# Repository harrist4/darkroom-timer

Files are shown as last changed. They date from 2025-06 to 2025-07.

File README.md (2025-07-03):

# Darkroom Dual Timer

A USB-powered stopwatch + countdown timer designed for darkroom and general timing tasks.  
Features a clear LED display, tactile button interface, audible feedback, and ultra-low sleep mode.

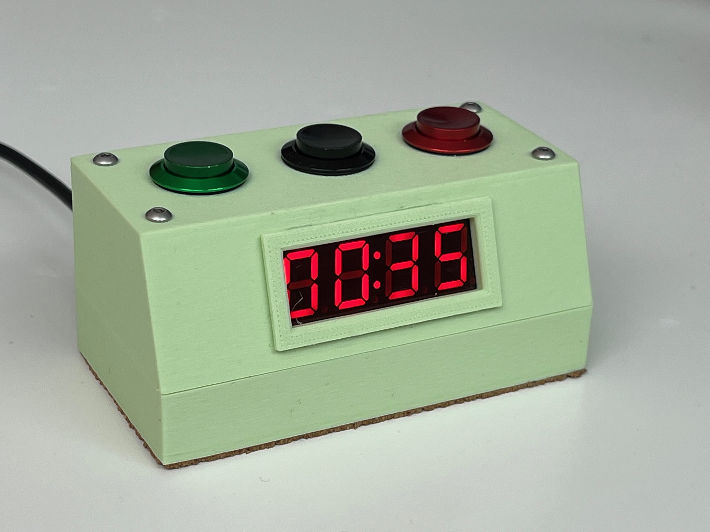
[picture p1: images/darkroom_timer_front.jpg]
Assembled Darkroom Timer


---

## Features

- Stopwatch and countdown timer modes
- Long-press and chord-based controls
- Sleep mode with wake-on-button
- Audible ticks and alarm tones
- Powered by any USB-C charger using an external 5V trigger module
- Clean UV-resin bezel, red optical gel

---

## Modes
### Global Controls
- **Green + Black** — Enable ticking
- **Red + Black** — Disable ticking
- **Green + Red** — Toggle between Stopwatch and Countdown (Alarm) modes
- **Red (D4, long press)** — Power off

### Stopwatch Mode
- **Green (D2)** — Start
- **Red (D4)** — Stop
- **Black (D3)** — Reset

### Countdown Timer Mode
- **Black (D3)** — Add 1 minute (tap), or rapid 5min increments (hold)
- **Black (D3, long press)** — Reset to 00:00
- **Green (D2)** — Start countdown
- **Red (D4)** — Stop countdown

---

## Wiring Summary

| Arduino Pin | Function | Notes |
|---|---|---|
| D2 * | Green Button | Start / wake / tick toggle (INT0: wake from sleep) |
| D3 * | Black Button | Add time / reset timer (INT1: wake from sleep) |
| D4 | Red Button | Stop / sleep / mode toggle |
| D5 | Buzzer | Passive buzzer tone output |
| D6 | TM1637 CLK | 4-digit display clock |
| D7 | TM1637 DIO | 4-digit display data |

\* Pins D2 and D3 are used for sleep wake interrupts INT0 and INT1

- Buttons are connected to GND and use `INPUT_PULLUP`
- Buzzer connects to D5 and GND
- Display uses TM1637 2-wire serial

---

## Power

- Powered via 5V USB-C trigger module
- USB-C powers Nano and display via 5V/GND pins
- Nano’s onboard USB port is unused
- Ideal for portable, battery-backed use

---

## 3D Printed Case

- STL files in `/3D/` folder
  - Top: `darkroom-timer-Case Top.stl`
  - Bottom: `darkroom-timer-Case Bottom.stl`
  - Bezel: `darkroom-timer-Bezel.stl` (step-backed for UV resin)

### Assembly Notes
- Internal parts secured with hot glue (release with IPA)
- Bezel glued with Bondic UV resin into side groove
- Red lighting gel sits under bezel over LED display

---

## Files

- `Arduino/DarkroomDualTimer/DarkroomDualTimer.ino`
- `3D/*.stl` and FreeCAD source
- `parts_list.md` with all required materials

### Required Arduino Libraries

This project depends on two Arduino libraries:

- **TM1637Display** by Avishorp — for driving the 4-digit LED display
- **ezButton** by ArduinoGetStarted — for reliable button press handling and debouncing

To install these libraries:

1. Open the Arduino IDE
2. Go to **Sketch → Include Library → Manage Libraries...**
3. In the Library Manager:
   - Search for **“TM1637Display”** and click **Install**
   - Search for **“ezButton”** and click **Install**

Alternatively, if you're using the Arduino CLI:

```bash
arduino-cli lib install "TM1637Display"
arduino-cli lib install "ezButton"
```

Make sure these libraries are available in your environment before compiling the sketch.

---

For parts, assembly tips, and adhesive guidance, see [`parts_list.md`](parts_list.md).

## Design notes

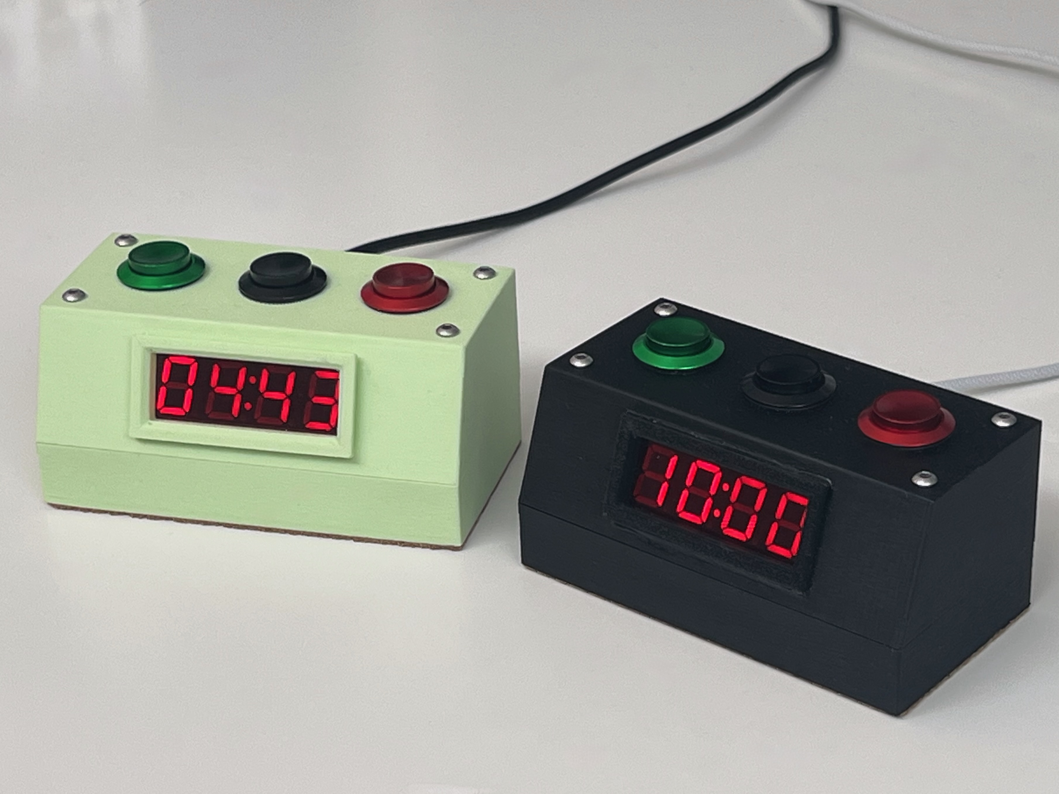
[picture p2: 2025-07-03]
images/darkroom_timers.jpeg

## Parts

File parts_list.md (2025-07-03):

# Parts List for Darkroom Timer Project

This project uses commonly available components to build a USB-powered stopwatch-style darkroom timer with a 4-digit LED display, audible tick, and a 3-button interface.

---

## Core Components

- **Arduino Nano V3.0** — ATmega328P with CH340 USB interface
- **Nano I/O Shield** — Terminal adapter expansion board for clean wiring
- **TM1637 4-Digit Display Module** — 0.56" red LED with built-in serial driver
- **Passive Buzzer** — 5V electromagnetic beeper (e.g., CYT1008)
- **Momentary Push Buttons (x3)** — 19mm metal, SPST, momentary action, screw terminal (Red, Green, Black)
- **USB-C Power Trigger Module** — Converts power from a USB-C charger into a steady 5V output for the timer (e.g., AITRIP 5A USB-C PD trigger board)

---

## Mounting and Wiring

- **M3 Screws (x4)** — Used to assemble the case
- **M3 Threaded Inserts (x4)** — Heat-set into plastic for secure case fastening
- **Adhesive Cork Sheet** — 1mm thick, applied to base for grip and surface protection
- **Wiring** — Flexible stranded hookup wire; connectors are up to builder preference

---

## Optical Component

- **Red Lighting Gel Filter** — 8.5" x 11" transparent red correction gel for safelight compatibility  
  - Example: *Transparent Color Red Correction Lighting Gel Filter 8.5 x 11-Inches Red Gel Light Filter Plastic Film Sheets*

---

## Adhesives and Assembly Aids

- **Hot Glue** — Used to secure internal components (Nano, display, USB-C module) to the case interior  
  - Easily released with a spray of isopropyl alcohol (IPA)
- **Bondic UV Resin Kit** — Used to affix the bezel cleanly without fogging or warping the red gel  
  - UV-accessible groove in the bezel makes this straightforward

---

## STL and Source Files

- FreeCAD source and STL files are located in the `3D/` directory  
  - Bezel: `darkroom-timer-Bezel.stl` (stepped design for UV resin)
  - Top/Bottom Case: `darkroom-timer-Case Top.stl`, `darkroom-timer-Case Bottom.stl`
- Arduino sketches are located in the `Arduino/` directory  
  - Main project: `Arduino/DarkroomDualTimer/DarkroomDualTimer.ino`
  - Demo/test sketch: `Arduino/VIsForVictory/VIsForVictory.ino`

---

For assembly instructions, wiring diagrams, and additional images, see the `README.md`.

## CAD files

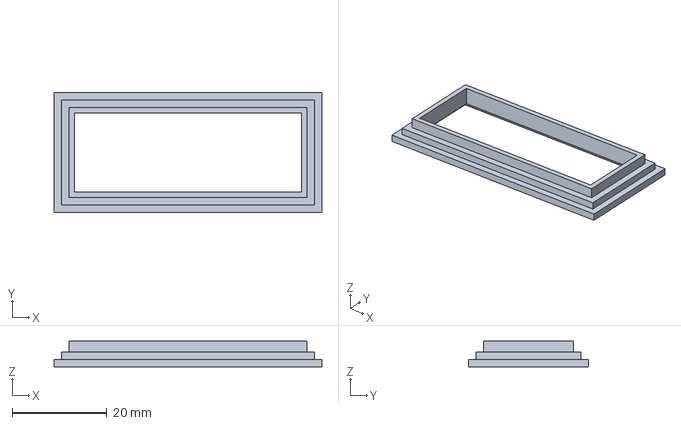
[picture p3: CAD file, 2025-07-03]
3D/darkroom-timer.FCStd
56.5 x 25.4 x 5.46 mm

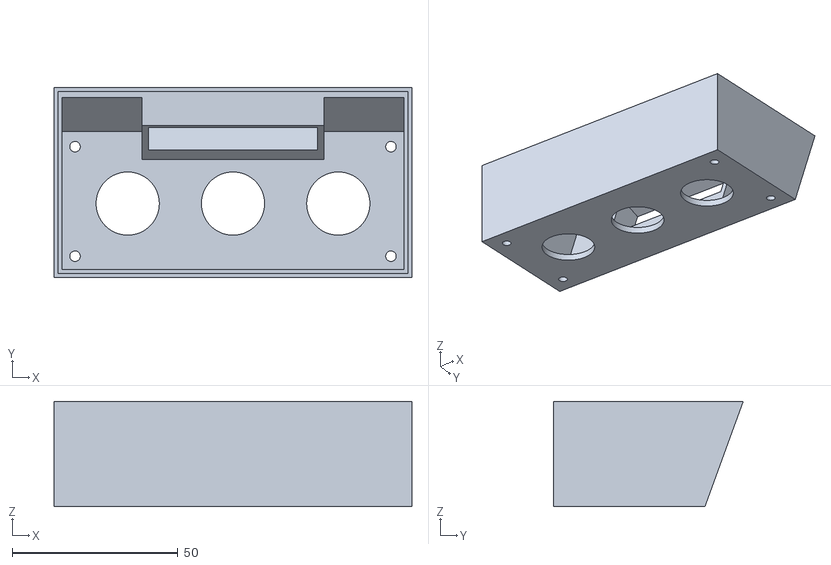
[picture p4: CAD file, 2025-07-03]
3D/darkroom-timer-Case Top.stl
107.9 x 57.2 x 31.8

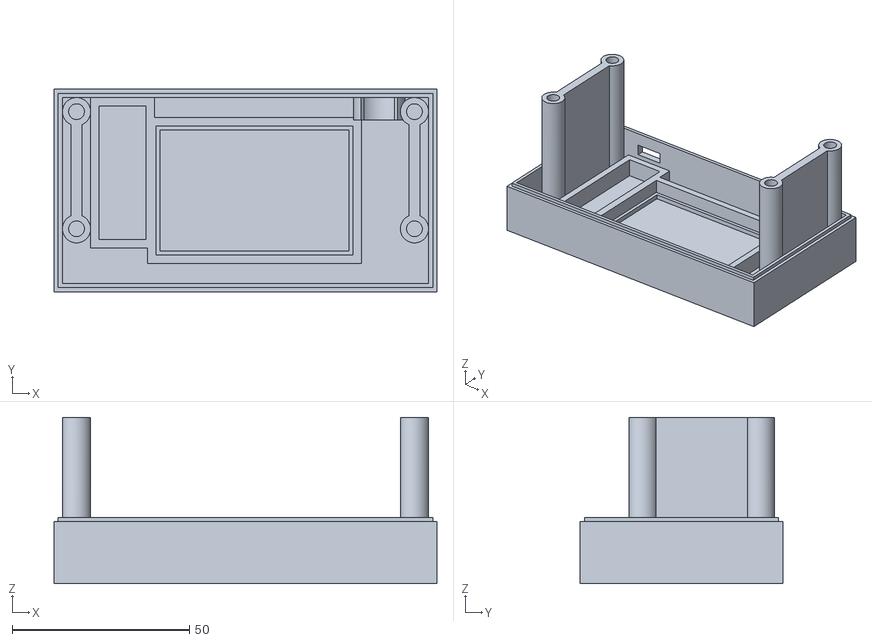
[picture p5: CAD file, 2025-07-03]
3D/darkroom-timer-Case Bottom.stl
107.9 x 57.2 x 46.8

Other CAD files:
3D/darkroom-timer-Bezel.stl

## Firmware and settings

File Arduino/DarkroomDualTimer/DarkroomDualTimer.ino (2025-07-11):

// ==================================================
// DarkroomDualTimer.ino
// Combined Stopwatch + Countdown Timer for Darkroom
// Features: mode switching, arpeggio tones, TM1637 display
// ==================================================

#include <ezButton.h>
#include <TM1637Display.h>
#include <EEPROM.h>
#include <avr/sleep.h>

// === CONFIGURATION ===
const int EEPROM_ADDR_MODE = 0;       // stores currentMode
const int EEPROM_ADDR_TICK = 1;       // stores tickEnabled
const int EEPROM_ADDR_INIT     = 100;  // a safe location for our marker
const byte EEPROM_MAGIC_VALUE = 0x42; // arbitrary non-zero value

const int NUM_BUTTONS = 3;
const unsigned long LONG_PRESS_THRESHOLD_MILLIS = 500UL;
const unsigned long CHORD_TIME_WINDOW_MILLIS = 100UL;

const unsigned long TICK_INTERVAL_MILLIS = 1000UL; // Timer tick every second

const unsigned long STOPWATCH_STOPPED_RESET_MILLIS = 30UL * 1000UL; // Time after stop when timer resets automatically
const unsigned long IDLE_SLEEP_TIMEOUT_MILLIS = 30UL * 60UL * 1000UL; // 30 minutes

const unsigned long TIMER_ALARM_PULSE_MILLIS = 50UL;  // Duration of each beep in the alarm (ms)
const unsigned long TIMER_ALARM_GAP_MILLIS = 50UL;    // Pause between beeps in alarm
const uint8_t TIMER_ALARM_PULSE_COUNT = 3;    // Number of beeps in each alarm burst
const unsigned int TIMER_ALARM_TONE_HZ = 1760;        // Frequency of the alarm tone in Hz
const uint16_t TIMER_ALARM_MAX_SECONDS = 5;   // Alarm duration (after this, screen flashes silently)
const bool TIMER_ALARM_DEBUG = false;     // If true, lets you test alarm manually at 00:00
const unsigned long VLP_THRESHOLD_MILLIS = 1200UL;  // 1.5 seconds
const unsigned long FAST_INCREMENT_INTERVAL_MILLIS = 200UL;  // Increment 4 times per second
const uint8_t FAST_INCREMENT_MINUTES = 5; // 5 minutes per interval

// === PINS ===
// Using Green and Black on 2 and 3 to allow them to interrupt sleep
const int buttonPins[NUM_BUTTONS] = {2, 4, 3};  // Green, Red, Black
const int CLK = 6;
const int DIO = 7;
const int LED_BRIGHTNESS = 0;
const int BUZZER_PIN = 5;
enum ButtonID { GREEN = 0, RED = 1, BLACK = 2 };
const char* buttonNames[NUM_BUTTONS] = { "Green", "Red", "Black" };

TM1637Display display(CLK, DIO);

enum TimerMode {
  MODE_STOPWATCH,
  MODE_TIMER
};

TimerMode currentMode = MODE_STOPWATCH;


// === Device Variables ===
bool tickEnabled = true;                // Clock ticks
volatile bool wakeFromSleepTriggered0 = false;
volatile bool wakeFromSleepTriggered1 = false;
unsigned long lastInteractionMillis = 0;

// === Stopwatch Variables ===
unsigned long stopwatchStartMillis = 0;          // Start time of current session
unsigned long stopwatchLastDeltaSeconds = 0;     // Last second tracked for updates
unsigned long stopwatchStopMillis = 0;           // Stop time of current session
uint16_t stopwatchDisplaySeconds = 0;                 // Time currently displayed (in seconds)
bool stopwatchRunning = false;

// === Timer Variables ==
unsigned long timerMillis = 0;  // Current countdown time in milliseconds
unsigned long timerLastTick = 0;         // When the last second tick occurred
uint8_t timerSetMinutes = 0;        // Time to count down from (set by user)
uint8_t timerSetSeconds = 0;
uint8_t timerLastSetMinutes = 0;        // Time to count down from (set by user)
uint8_t timerLastSetSeconds = 0;
bool timerColonOn = false;
bool timerLastColonOn = false;
bool blackVeryLongPressActive = false;
unsigned long lastFastAddTime = 0;
bool minuteTonePlayed = false;

// Alarm State
bool timerAlarmActive = false;   // Is the alarm currently sounding?
bool timerAlarmToneOn = false;   // Is the beep tone currently playing?
unsigned long timerAlarmTimer = 0; // Time alarm started

// Timer State
enum CountdownState { SETUP, RUNNING, PAUSED, ALARM, OFF }; // Different modes the timer can be in
CountdownState countdownState = SETUP;         // Start in SETUP mode

// === STRUCTS ===
struct ButtonState {
  ezButton button;
  unsigned long pressedAt = 0;
  unsigned long releasedAt = 0;
  bool isPressed = false;
  bool wasHandled = false;
  ButtonState(int pin) : button(pin) {}
};

struct PressEvents {
  bool redShortPress = false;
  bool redLongPress = false;
  bool greenShortPress = false;
  bool greenLongPress = false;
  bool blackShortPress = false;
  bool blackLongPress = false;

  bool redBlackShortPress = false;
  bool redBlackLongPress = false;
  bool greenBlackShortPress = false;
  bool greenBlackLongPress = false;
  bool redGreenShortPress = false;
  bool redGreenLongPress = false;

  bool greenRedBlackShortPress = false;
  bool greenRedBlackLongPress = false;

  void reset() { *this = PressEvents(); }
};

// === GLOBAL STATE ===
ButtonState* buttons[NUM_BUTTONS] = {
  new ButtonState(buttonPins[GREEN]),
  new ButtonState(buttonPins[RED]),
  new ButtonState(buttonPins[BLACK])
};
PressEvents pressEvents;

// === PROTOTYPES ===
void doResetStopwatch();
void doResetTimer();
void doReset();

// === INITIALIZATION ===
void loadSettings() {
  byte marker = EEPROM.read(EEPROM_ADDR_INIT);

  if (marker != EEPROM_MAGIC_VALUE) {
    // First time setup
    currentMode = MODE_STOPWATCH;
    tickEnabled = true;

    EEPROM.update(EEPROM_ADDR_MODE, currentMode);
    EEPROM.update(EEPROM_ADDR_TICK, tickEnabled ? 1 : 0);
    EEPROM.update(EEPROM_ADDR_INIT, EEPROM_MAGIC_VALUE);
  } else {
    // Load previously saved values
    byte modeByte = EEPROM.read(EEPROM_ADDR_MODE);
    currentMode = (modeByte == MODE_TIMER) ? MODE_TIMER : MODE_STOPWATCH;

    byte tickByte = EEPROM.read(EEPROM_ADDR_TICK);
    tickEnabled = (tickByte != 0);
  }
}

void wakeFromSleepInterrupt0() {
  wakeFromSleepTriggered0 = true;              // Just set the flag
}
void wakeFromSleepInterrupt1() {
  wakeFromSleepTriggered1 = true;              // Just set the flag
}
void enterSleepMode() {
  // ✅ Show "OFF" before sleeping
  uint8_t offMessage[4] = {
    0x3F,  // O
    0x71,  // F
    0x71,  // F
    0x00   // (blank)
  };
  display.setSegments(offMessage);
  doubleTick();

  // Prepare for sleep
  display.clear();       // Blank display to reduce draw
  noTone(BUZZER_PIN);    // Ensure buzzer is silent

  // Set sleep mode
  set_sleep_mode(SLEEP_MODE_PWR_DOWN);
  sleep_enable();

  // Ensure no interrupts before attaching
  noInterrupts();
  attachInterrupt(digitalPinToInterrupt(2), wakeFromSleepInterrupt0, LOW);
  attachInterrupt(digitalPinToInterrupt(3), wakeFromSleepInterrupt1, LOW);
  interrupts();

  sleep_cpu();  // 💡 The Nano actually sleeps here

  // 💤 ... Wakes up here ...
  sleep_disable();
  detachInterrupt(digitalPinToInterrupt(2));
  detachInterrupt(digitalPinToInterrupt(3));

  doReset();
}
void setup() {
  loadSettings();

  for (int i = 0; i < NUM_BUTTONS; i++) {
    buttons[i]->button.setDebounceTime(50);
    pinMode(buttonPins[i], INPUT_PULLUP);
  }
  display.setBrightness(LED_BRIGHTNESS);
  doReset();
}

void loop() {
  pressEvents.reset();

  for (int i = 0; i < NUM_BUTTONS; i++) {
    buttons[i]->button.loop();

    if (buttons[i]->button.isPressed()) {
      buttons[i]->pressedAt = millis();
      buttons[i]->isPressed = true;
      buttons[i]->wasHandled = false;
    }

    if (buttons[i]->button.isReleased()) {
      buttons[i]->releasedAt = millis();
      buttons[i]->isPressed = false;
    }
  }

  resolveEventsIfReady();

  // This has to happen after the "wake from sleep" logic so that
  // the lastInteractionMillis has been updated by the reset post-wake
  // to avoid some crazy can't wake up scenario.
  bool shouldSleepForInactivity = (millis() - lastInteractionMillis > IDLE_SLEEP_TIMEOUT_MILLIS);

  // Handle global buttons

  if(pressEvents.redGreenShortPress) {
    toggleMode();
    return;
  }

  if(pressEvents.redLongPress || shouldSleepForInactivity){
    enterSleepMode();
    return;
  }

  if(tickEnabled){
    if(pressEvents.redBlackShortPress){
      toggleTick();
      return;
    }
  }else{
    if(pressEvents.greenBlackShortPress){
      toggleTick();
      return;
    }
  }

  switch(currentMode){
    case MODE_STOPWATCH:
      stopwatchLoop();
      break;
    case MODE_TIMER:
      timerLoop();
      break;
    default:
      break;
  }
  delay(1);
}

// Global means of determine if something is running
boolean isRunning(){
  switch(currentMode){
    case MODE_STOPWATCH:
      return stopwatchRunning;
      break;
    case MODE_TIMER:
      return countdownState == RUNNING;
      break;
    default:
      return false;
      break;
  }
}

void doReset(){
  // No matter what, if we are resetting, we don't want the thing
  // to think it needs to shut off because it has timed out.
  lastInteractionMillis = millis();
  display.setBrightness(LED_BRIGHTNESS);
  // display.clear();
  noTone(BUZZER_PIN);
  
  switch(currentMode){
    case MODE_STOPWATCH:
      doResetStopwatch();
      break;
    case MODE_TIMER:
      doResetTimer();
      break;
    default:
      break;
  }
}

void toggleMode(){
  if (currentMode == MODE_TIMER) {
    currentMode = MODE_STOPWATCH;
    playStopwatchModeTone();
    doResetStopwatch();
  }else{
    currentMode = MODE_TIMER;
    playCountdownModeTone();
    doResetTimer();
  }
  EEPROM.update(EEPROM_ADDR_MODE, currentMode);
}

void toggleTick(){
  if(tickEnabled){
    playDescendingArpeggio();
    tickEnabled = false;
  }else{
    playAscendingArpeggio();
    tickEnabled = true;
  }
  EEPROM.update(EEPROM_ADDR_TICK, tickEnabled ? 1 : 0);
}

// ============================================
// Stopwatch Mode
// ============================================
void stopwatchLoop(){
  if(pressEvents.blackShortPress){
    bool wasRunning = stopwatchRunning;
    doResetStopwatch();
    if(wasRunning){
      playShortTone();
      stopwatchStartMillis = millis();
      stopwatchRunning = true;
    }
  }
  if(stopwatchRunning){
    if(pressEvents.redShortPress){
      stopwatchRunning = false;
      stopwatchStopMillis = millis();
    }
  }else{
    if(pressEvents.greenShortPress){
      minuteTonePlayed = true;
      stopwatchStartMillis = millis();
      stopwatchLastDeltaSeconds = 0;
      stopwatchRunning = true;
    }
  }
  unsigned long currentMillis = millis();
  unsigned long deltaMillis = currentMillis - stopwatchStartMillis;
  unsigned long deltaSeconds = deltaMillis / 1000;

  boolean colonOn = stopwatchRunning ? (deltaMillis % 1000 < 500) : true;  // Blink colon if running

  if(stopwatchRunning){
    // We're doing something. Don't sleep!  
    lastInteractionMillis = millis();
  }

  if (stopwatchRunning && deltaSeconds > stopwatchLastDeltaSeconds) {
    stopwatchLastDeltaSeconds++;
    stopwatchDisplaySeconds++;
    tick();  // Tick sound
  }

  // If stopped, wait 10 seconds, then automatically clear to zero
  if(!stopwatchRunning && stopwatchStopMillis > 0 && millis() - stopwatchStopMillis > STOPWATCH_STOPPED_RESET_MILLIS){
    doubleTick();
    doReset();
  }

  // Display time as MM:SS
  uint8_t minutes = stopwatchDisplaySeconds / 60;
  uint8_t seconds = stopwatchDisplaySeconds % 60;
  if(stopwatchRunning){
    if(minutes > 0 && seconds == 0){
      if(!minuteTonePlayed){
        playMinuteTone();
        minuteTonePlayed = true;
      }
    }else{
      minuteTonePlayed = false;
    }
  }

  uint16_t timeVal = minutes * 100 + seconds;
  display.showNumberDecEx(timeVal, colonOn ? 0b01000000 : 0, true);
}

void doResetStopwatch(){
  stopwatchRunning = false;
  stopwatchStartMillis = 0;
  stopwatchDisplaySeconds = 0;
  stopwatchLastDeltaSeconds = 0;
  stopwatchStopMillis = 0;
  display.showNumberDecEx(0, 0b01000000, true); // Reset to 00:00
}

// ============================================
// Timer Mode
// ============================================
void timerLoop(){
  handleTimerButtons();

  // Special case for very long press of black
  // There really has to be a better place for this!
  if (countdownState == SETUP) {
    bool blackHeld = !digitalRead(buttonPins[BLACK]);  // active low

    if (blackHeld) {
      unsigned long heldTime = millis() - buttons[BLACK]->pressedAt;

      // Sanity cap: if the device just woke from sleep, skip obviously stale times
      if (buttons[BLACK]->pressedAt > 0 && heldTime > VLP_THRESHOLD_MILLIS){
        blackVeryLongPressActive = true;

        if (millis() - lastFastAddTime > FAST_INCREMENT_INTERVAL_MILLIS) {
          // Go backwards to trim off any unsightly minutes not on a multiple of FAST_INCREMENT_MINUTES
          timerSetMinutes = timerSetMinutes - timerSetMinutes%FAST_INCREMENT_MINUTES;
          // Now add FAST_INCREMENT_MINUTES minutes.
          timerSetMinutes += FAST_INCREMENT_MINUTES;
          timerSetMinutes = min(timerSetMinutes, 99);
          quietTick();
          updateTimerDisplay();
          lastFastAddTime = millis();
        }
      }
      return;
    } else {
      blackVeryLongPressActive = false;
    }
  }

  unsigned long now = millis();

  
// === Blink the colon on and off once per second in RUNNING mode ===
  if (countdownState == RUNNING) {
    // We're doing something. Don't sleep!  
    lastInteractionMillis = millis();

    unsigned long phase = now - timerLastTick;
    timerColonOn = (phase < 500);
    if (timerColonOn != timerLastColonOn) {
      timerLastColonOn = timerColonOn;
      updateTimerDisplay();
    }
  } else {
    // Colon stays ON in other modes
    if (!timerColonOn) {
      timerColonOn = true;
      timerLastColonOn = true;
      updateTimerDisplay();
    }
  }

  // === Countdown logic: subtract 1 second every tick ===
  if (countdownState == RUNNING && now - timerLastTick >= TICK_INTERVAL_MILLIS) {
    timerLastTick = now;
    tick(); // short tick sound

    if (timerMillis >= TICK_INTERVAL_MILLIS) {
      timerMillis -= TICK_INTERVAL_MILLIS;
      updateTimerDisplay();
    } else {
      countdownState = ALARM;
      timerSetMinutes = timerLastSetMinutes;
      timerSetSeconds = timerLastSetSeconds;
      startTimerAlarm();
      updateTimerDisplay();
    }
  }

  // === ALARM: sound 3 short beeps per second ===
  if (countdownState == ALARM && timerAlarmActive) {
    unsigned long alarmMillis = (millis() - timerAlarmTimer);
    unsigned long windowMillis = alarmMillis % 1000;

    unsigned long soundDuration = TIMER_ALARM_PULSE_COUNT * TIMER_ALARM_PULSE_MILLIS +
                                  (TIMER_ALARM_PULSE_COUNT - 1) * TIMER_ALARM_GAP_MILLIS;

    bool found = false;
    if (alarmMillis / 1000 < TIMER_ALARM_MAX_SECONDS) {
      if (windowMillis < soundDuration) {
        for (int i = 0; i < TIMER_ALARM_PULSE_COUNT; i++) {
          int leadingEdge = i * (TIMER_ALARM_PULSE_MILLIS + TIMER_ALARM_GAP_MILLIS);
          int trailingEdge = TIMER_ALARM_PULSE_MILLIS + i * (TIMER_ALARM_PULSE_MILLIS + TIMER_ALARM_GAP_MILLIS);
          if (leadingEdge < windowMillis && windowMillis < trailingEdge) {
            found = true;
            break;
          }
        }
        if (found && !timerAlarmToneOn) {
          tone(BUZZER_PIN, TIMER_ALARM_TONE_HZ, TIMER_ALARM_PULSE_MILLIS);
          timerAlarmToneOn = true;
        }
      }
    }

    if (!found) {
      noTone(BUZZER_PIN);
      timerAlarmToneOn = false;
    }

    updateTimerDisplay();  // blink effect during alarm
  }

  
// === Turn off display in OFF mode ===
  if (countdownState == OFF) {
    display.clear();
  }
}

void doResetTimer(){
  // Clear VLP state
  blackVeryLongPressActive = false;
  lastFastAddTime = 0;
  resetAllButtons();
  // Reset other stuff
  timerSetMinutes = 0;
  timerSetSeconds = 0;
  timerLastSetMinutes = 0;
  timerLastSetSeconds = 0;
  // timerSetMinutes = timerLastSetMinutes;
  // timerSetSeconds = timerLastSetSeconds;
  timerMillis = 0;
  timerAlarmActive = false;
  countdownState = SETUP;
  updateTimerDisplay();
}


// === CHECK BUTTONS ===
// Handles logic for button presses, including short and long presses
void handleTimerButtons() {

  // === GREEN button: Start, Resume, or Trigger Alarm in DEBUG mode ===
  if (pressEvents.greenShortPress) {
    // No matter what, avoid playing the minute tone right away
    minuteTonePlayed = true;

    // If timer is in ALARM, stop alarm and use last time if possible
    if (countdownState == ALARM){
      stopTimerAlarm();
      timerSetMinutes = timerLastSetMinutes;
      timerSetSeconds = timerLastSetSeconds;
      countdownState = SETUP;
    }
    // If timer says zero in SETUP, use last time if possible
    if(countdownState == SETUP && (timerSetMinutes == 0) && (timerSetSeconds == 0)){
      timerSetMinutes = timerLastSetMinutes;
      timerSetSeconds = timerLastSetSeconds;
    }
    if (countdownState == SETUP && (timerSetMinutes > 0 || timerSetSeconds > 0)) {
      timerMillis = (timerSetMinutes * 60UL + timerSetSeconds) * 1000UL;
      timerLastTick = millis();
      countdownState = RUNNING;
      timerLastSetMinutes = timerSetMinutes;
      timerSetMinutes = 0;
      timerLastSetSeconds = timerSetSeconds;
      timerSetSeconds = 0;
    } else if (countdownState == PAUSED) {
      countdownState = RUNNING;
      timerLastTick = millis();
    }
  }

  if (pressEvents.blackShortPress) {
    switch(countdownState){
      case OFF:
        countdownState = SETUP;
        timerSetMinutes = 1;
        timerSetSeconds = 0;
        updateTimerDisplay();
        break;
      case SETUP:
        timerSetMinutes = (timerSetMinutes + 1) % 100;
        timerSetSeconds = 0;
        updateTimerDisplay();
        break;
      case PAUSED:
        timerMillis = 0;
        countdownState = SETUP;
        timerSetMinutes = timerLastSetMinutes;
        timerSetSeconds = timerLastSetSeconds;
        updateTimerDisplay();
        break;
      case RUNNING:
        // Add a minute to running timer
        playShortTone();
        timerMillis += 60UL * 1000UL;
        break;
      case ALARM:
        stopTimerAlarm();
        countdownState = SETUP;
        timerMillis = 0;
        timerSetMinutes = (timerSetMinutes + 1) % 100;
        timerSetSeconds = 0;
        updateTimerDisplay();   
        break;
    }
  }

  if (pressEvents.blackLongPress) {
    switch(countdownState) {
      case SETUP:
        timerSetMinutes = 0;
        timerSetSeconds = 0;
        updateTimerDisplay();
        break;
      case PAUSED:
        timerMillis = 0;
        countdownState = SETUP;
        updateTimerDisplay();
        break;
    }    
  }

  // === RED button: Short = stop/pause, Long = power off ===
  if (pressEvents.redShortPress) {
    switch (countdownState) {
      case RUNNING:
        countdownState = PAUSED;
        break;
      case ALARM:
        stopTimerAlarm();
        countdownState = SETUP;
        timerMillis = 0;
        updateTimerDisplay();
        break;
      default:
        break;
    }
  }
  if(pressEvents.redLongPress){
    stopTimerAlarm();
    countdownState = OFF;
    playQuietDoubleClick();
  }
}


// === Start alarm sequence ===
void startTimerAlarm() {
  timerAlarmActive = true;
  timerAlarmTimer = millis();
  timerAlarmToneOn = false;
}


// === Stop alarm sequence ===
void stopTimerAlarm() {
  timerAlarmActive = false;
  timerAlarmTimer = 0;
  noTone(BUZZER_PIN);
  timerAlarmToneOn = false;
}

// === Update display based on current timer or alarm ===
void updateTimerDisplay() {
  if (countdownState == OFF) return;

  // Flash the display during alarm
  if (timerAlarmActive) {
    if ((timerAlarmTimer - millis()) % 500 > 250) {
      display.clear();
      return;
    }
  }

  uint8_t minutes = 0;
  uint8_t seconds = 0;

  if (countdownState == SETUP || countdownState == ALARM) {
    minutes = timerSetMinutes;
    seconds = timerSetSeconds;
  } else {
    unsigned long timeLeft = timerMillis / 1000;
    minutes = timeLeft / 60;
    seconds = timeLeft % 60;
  }

  if(countdownState == RUNNING){
    if(minutes > 0 && seconds == 0){
      if(!minuteTonePlayed){
        playMinuteTone();
        minuteTonePlayed = true;
      }
    }else{
      minuteTonePlayed = false;
    }
  }

  uint8_t colon = timerColonOn ? 0b01000000 : 0;

  if (minutes < 10) {
    // Show M:SS (3 digits, no leading zero)
    uint8_t digits[4] = {0, 0, 0, 0};

    // Map digits manually
    digits[1] = display.encodeDigit(minutes);
    digits[2] = display.encodeDigit(seconds / 10);
    digits[3] = display.encodeDigit(seconds % 10);

    if (colon) {
      digits[1] |= 0b10000000;  // add colon between digit 1 and 2
    }

    display.setSegments(digits);
  } else {
    // Show MM:SS normally (4 digits, leading digit visible)
    display.showNumberDecEx(minutes * 100 + seconds, colon, true);
  }
}
//
// === BUTTON EVENT HANDLER
//
void resetAllButtons() {
  for (int i = 0; i < NUM_BUTTONS; i++) {
    buttons[i]->pressedAt = 0;
    buttons[i]->releasedAt = 0;
    buttons[i]->wasHandled = false;
  }
}
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

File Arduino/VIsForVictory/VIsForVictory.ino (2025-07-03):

const int LED_PIN = 13;
const int DOT = 200;
const int DASH = DOT * 3;
const int GAP = DOT;

void setup() {
  pinMode(LED_PIN, OUTPUT);
}

void loop() {
  // Morse "V" = ...-
  blink(DOT);
  blink(DOT);
  blink(DOT);
  blink(DASH);

  delay(2000); // Pause before repeating
}

void blink(int duration) {
  digitalWrite(LED_PIN, HIGH);
  delay(duration);
  digitalWrite(LED_PIN, LOW);
  delay(GAP);
}
